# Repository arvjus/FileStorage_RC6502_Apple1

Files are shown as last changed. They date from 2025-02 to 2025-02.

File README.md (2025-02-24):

# FileStorage_RC6502_Apple1

This is a collection of HW / SW to provide file storage capabilty for RC6502 Apple1 Replica.
	
## Main Highlights
	* Uses W25Q64 chip to srore the data
	* Simple File system to keep files structured
	* Supported files: type $06 (regular binary), $F1 (Integer Basic, ProDOS file format)
	* Utility programs to prepare disk images or porsions of FS on regular OS (tested on Linux)			
	
## Status
	Quite stable, I use it on dayly basis
 
## Desired improvements
	* Better error handling. In most cases if user does input error or something unexpected happens in communication, the command is just silently ignored.
 	* Better performance in data transfer. It takes about 3 secs to load 1Kb of data.
 
## Screenshots
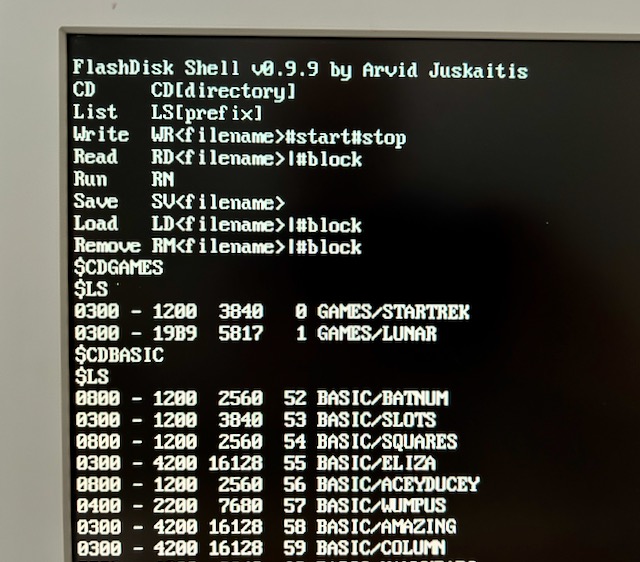
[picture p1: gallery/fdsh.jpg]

	
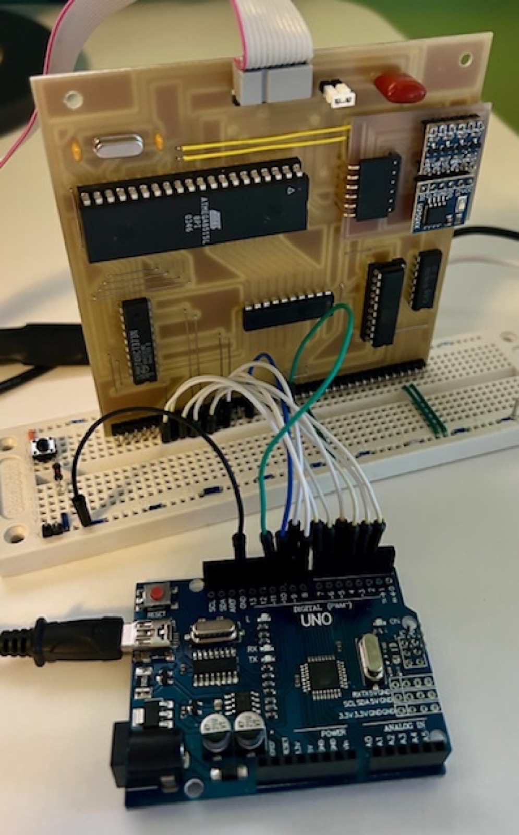
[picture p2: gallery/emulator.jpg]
emulator


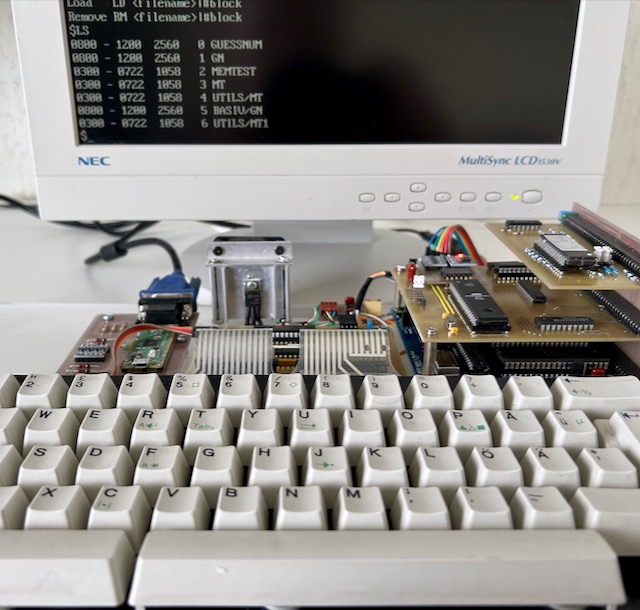
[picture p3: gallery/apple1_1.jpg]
apple1

	
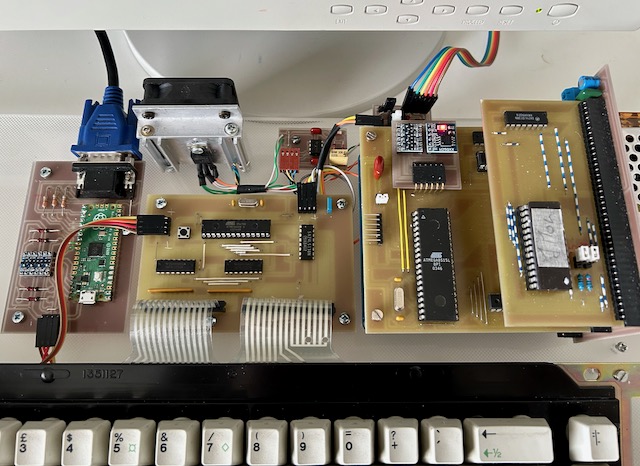
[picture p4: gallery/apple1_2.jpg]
apple1

	
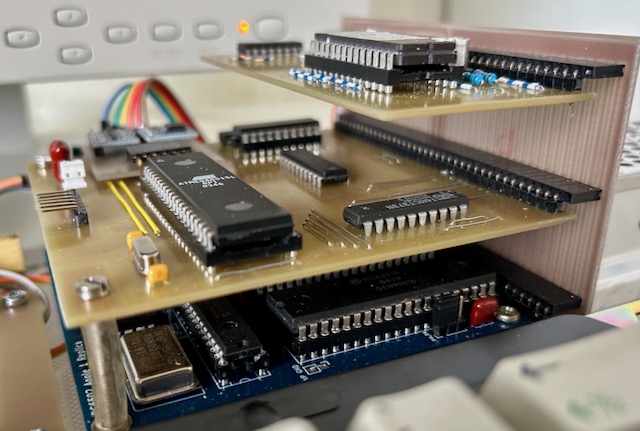
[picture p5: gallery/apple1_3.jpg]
apple1


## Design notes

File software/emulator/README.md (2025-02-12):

# CPU Emulator 

Purpose of this device is to speed up development/debugging of communication protocol and underlying file system routines. 
Based on Arduino Uno, accepts commands from serial input and communicates with RC6502_flash card, using defined data communication protocol.
Since there is only one address used ($c800), address lines can be hardwired, arduino generates /WR, PHI2 and data bus signals. 

Baud rate - 38400

emulator

##  Supported commands

### s
reads and displays byte on the data bus

### r
waits for RDY flag set, displays byte on the data bus in hex. Or reads another nibble if bytes has DAT bit set. 
For every byte received, it sends ACK automatically if received byte is other than ACK (no ACK on ACK).  

### R
similar to r, but loops until EODT is received. 

### wHH|wC
waits for BSY flag cleared, sends a byte HH in hex or two data nibbles of C.  

### a
sends ACK (0x90) byte

### n
sends NACK (0x9f) byte

### b
sends BODT (0x80) byte

### e
sends EODT (0x8f) byte

### l
print log data

### lr
reset log data

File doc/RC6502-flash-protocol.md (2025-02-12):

# RC6502 FLASH Device Data Exchange Protocol

## Overview
FLASH Device (W26Q64F) is driven by Atmega8515 MCU. This protocol ensures robust communication between the CPU and MCU, with clear mechanisms for synchronisation, acknowledgment, and error handling.

The CPU is responsible for initiating all data transfers. Communication occurs through a dedicated address range, currently set to $C800–$CFFF. There are two modes of operation: DATA and CTRL/STATUS, distinguished by the 5th bit of the byte it determines the byte type: if clear, it indicates a command (CPU) or status (MCU); if set, it represents a data nibble.

In CTRL/STATUS mode, the 5th bit is set to 0. Bits [3..0] carry commands (from the CPU) or status (from the MCU). The MCU provides two status flags: BSY (bit 6) indicates the MCU is busy, and RDY (bit 7) indicates data is ready. The CPU waits for BSY to clear before writing a byte and for RDY to be set before reading from register.

In DATA mode, the 5th bit is set to 1. Data is transmitted in nibbles using bits [3..0]. The most significant nibble (MSN) is sent first, followed by the least significant nibble (LSN).

When the CPU sends a command, the MCU replies with an ACK or NACK message. Note this is for only command, does not apply to data transfers. Similarly, when the MCU sends data to the CPU, the CPU must reply with an ACK for each byte received. If the CPU responds with NACK, the data transfer is aborted.

All data transmissions starts with begin-of-data-transfer (BODT) and concluded with an end-of-data-transfer (EODT) marker. BODT could be used to restart transmission, in some context this could mean separate data chunk, like file name and data in CMD_WRITE. If a new command is sent while a data transfer is in progress, it interrupts and cancels the current transmission.

```
## Status flags
RDY_FLAG  = (1 << 7)
BSY_FLAG  = (1 << 6)
ACK_FLAG  = (1 << 5)
DAT_FLAG  = (1 << 4)
```
```
## Commands
* CMD_LIST = 0x01     - list files. 
* CMD_WRITE = 0x02    - save data to disk. 
* CMD_READ = 0x03     - read data from disk. 
* CMD_DELETE = 0x04   - delete file.
* BODT = 0x80         - indicates the beginning of data transfer.
* EODT = 0x8F         - indicates the end of data transfer.
* ACK  = 0x90         - MCU confirms operation
* NACK = 0x9F         - MCU declines operation
```
Note in CMD_READ and CMD_DELETE commands it is possible to use block id instead of file name, eg. "#123"

## Design Issues
* Writing to MCU's input register. 6502 runs at 1 MHz clock speed, it writes to $c800 address in sync with /WR+PHI2, so we have less than 500ns window to read the data. When CPU writes data, data is latched an interrupt is triggered in MCU but IRQ latency and additional cycles delays reading for 1125ns, But after 500ns window LEWRITE- goes up and we must keep that signal low until data is read in ISR. One possible solution is to add RS latch and reset it from ISR after register is read.

## Low level data exchange protocol 
```
### CPU -> MCU
Wait for BSY is cleared
Write a command byte
Wait for RDY is set
Read a byte, ACK or NACK is expected
```
### MCU -> CPU
```
In ISR:
Set BSY, clear RDY
Read byte, check value- command, data nibble, ACK or NACK is expected
Update state in SM
If NACK is received - stop current operation.
Generate strobe CLEWRITE- to release latch
In main loop:
If a new command is initiate - start executing and return ACK or NACK
Otherwise continue with data transfer or put to idle.
```
## High level data exchange protocol

### CMD_LIST
```
; CPU rquests list all files starting with 't'
; MCU response with single file entry
; 0 Type - Unused=0, File=1, Executable=2
; 1 Block number - starting from 0
; 2-3 Length - number of bytes (little endian)
; 4-15 Name - case insensitive
; Type=File, Block=1, Length=10, Name=test.txt
CPU, MCU - CMD_LIST, ACK
CPU, MCU - BODT, ACK       	    ; File name search pattern
CPU, MCU - 0x97, ACK, 0x94, ACK ; File starts with 't'
CPU, MCU - EODT, ACK    	    ; Done
MCU, CPU - BODT, ACK            ; Start
MCU, CPU - 0x90, ACK, 0x91, ACK	; Type
MCU, CPU - 0x90, ACK, 0x91, ACK	; Block
MCU, CPU - 0x90, ACK, 0x9A, ACK	; Length LSB
MCU, CPU - 0x90, ACK, 0x90, ACK	; Length MSB
MCU, CPU - 0x97, ACK, 0x94, ACK	; 't'
MCU, CPU - 0x96, ACK, 0x95, ACK	; 'e'
MCU, CPU - 0x97, ACK, 0x93, ACK	; 's'
MCU, CPU - 0x97, ACK, 0x94, ACK	; 't'
MCU, CPU - 0x92, ACK, 0x9E, ACK	; '.'
MCU, CPU - 0x97, ACK, 0x94, ACK	; 't'
MCU, CPU - 0x97, ACK, 0x98, ACK	; 'x'
MCU, CPU - 0x97, ACK, 0x94, ACK	; 't'
MCU, CPU - EODT, ACK            ; Done
```

### CMD_WRITE
```
; write "test" string to "test.txt" file
CPU, MCU - CMD_WRITE, ACK
CPU - BODT, ACK      	; File name
CPU - 0x97, 0x94 	    ; 't'
CPU - 0x96, 0x95		; 'e'
CPU - 0x97, 0x93		; 's'
CPU - 0x97, 0x94		; 't'
CPU - 0x92, 0x9E		; '.'
CPU - 0x97, 0x94		; 't'
CPU - 0x97, 0x98		; 'x'
CPU - 0x97, 0x94		; 't'
CPU - EODT, ACK   	    ; MCU allocates file entry, could return NACK if name is invalid or no room left
CPU - BODT      		; File content
CPU - 0x97, 0x94		; 't'
CPU - 0x96, 0x95		; 'e'
CPU - 0x97, 0x93		; 's'
CPU - 0x97, 0x94		; 't'
CPU - EODT, ACK   	    ; Done
```

### CMD_READ
```
; read "empty" file
CPU, MCU - CMD_WRITE, ACK
CPU - BODT, ACK      	; File name
CPU - 0x96, 0x95		; 'e'
CPU - 0x96, 0x9D		; 'm'
CPU - 0x97, 0x90		; 'p'
CPU - 0x97, 0x94		; 't'
CPU - 0x97, 0x99		; 'y'
CPU - EODT, ACK   	; File found
MCU, CPU - BODT, ACK  ; File content
MCU, CPU - EODT, ACK  ; Done
```

### CMD_DELETE
```
; request delete non-existing file
CPU, MCU - CMD_WRITE, ACK
CPU - BODT, ACK      	; File name
CPU - 0x96, 0x9E		; 'n'
CPU - 0x96, 0x9F		; 'o'
CPU - 0x97, 0x90		; 'p'
CPU - 0x96, 0x95		; 'e'
MCU - NACK  		; File not found
```

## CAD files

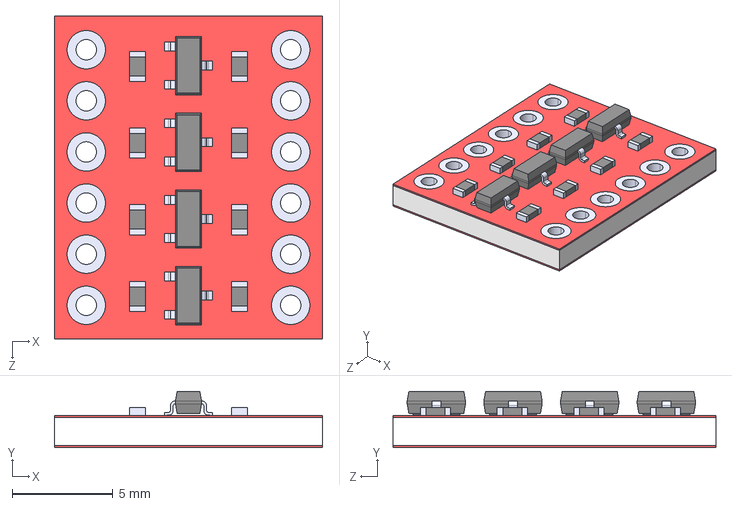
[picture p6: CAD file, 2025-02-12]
hardware/w25q64_spi/BOB-12009.step
13.3 x 2.80 x 16.1 mm

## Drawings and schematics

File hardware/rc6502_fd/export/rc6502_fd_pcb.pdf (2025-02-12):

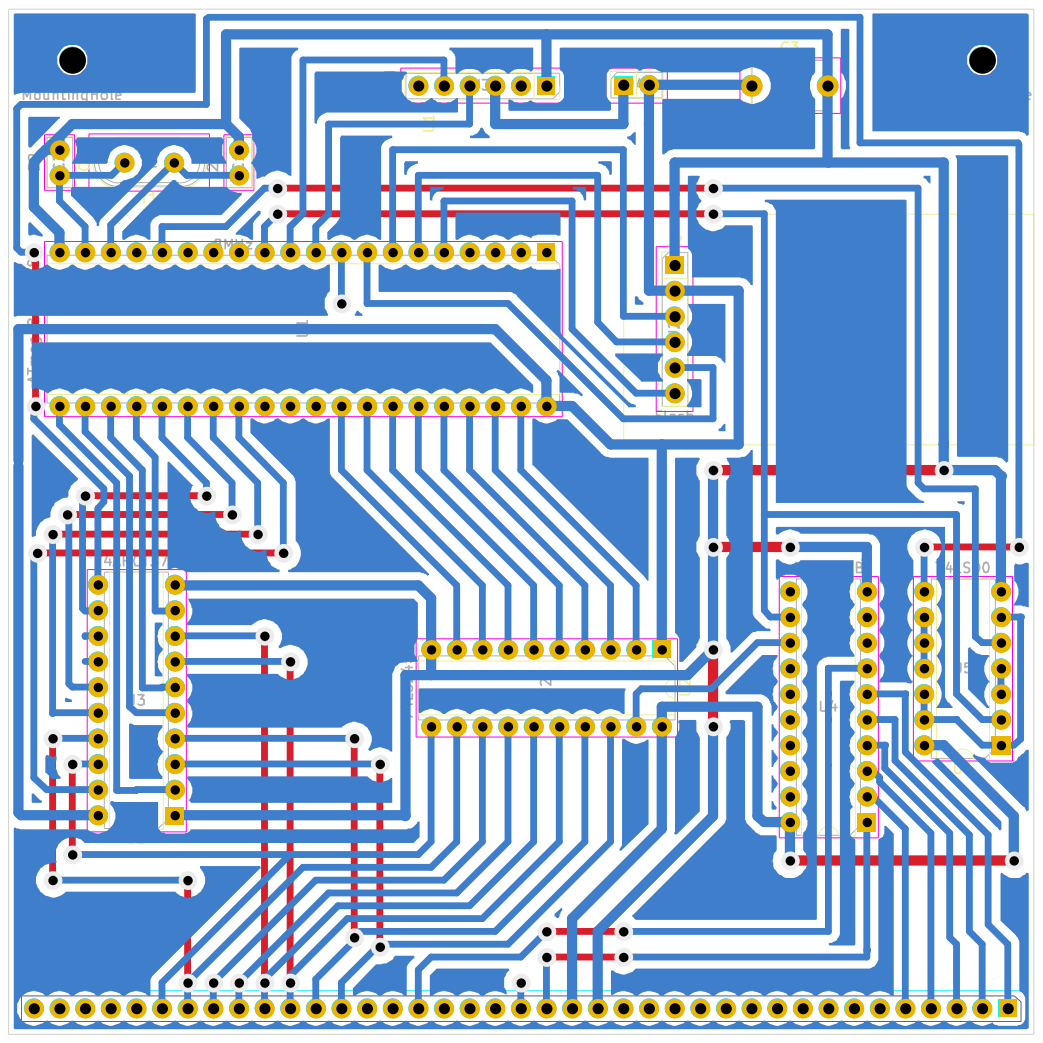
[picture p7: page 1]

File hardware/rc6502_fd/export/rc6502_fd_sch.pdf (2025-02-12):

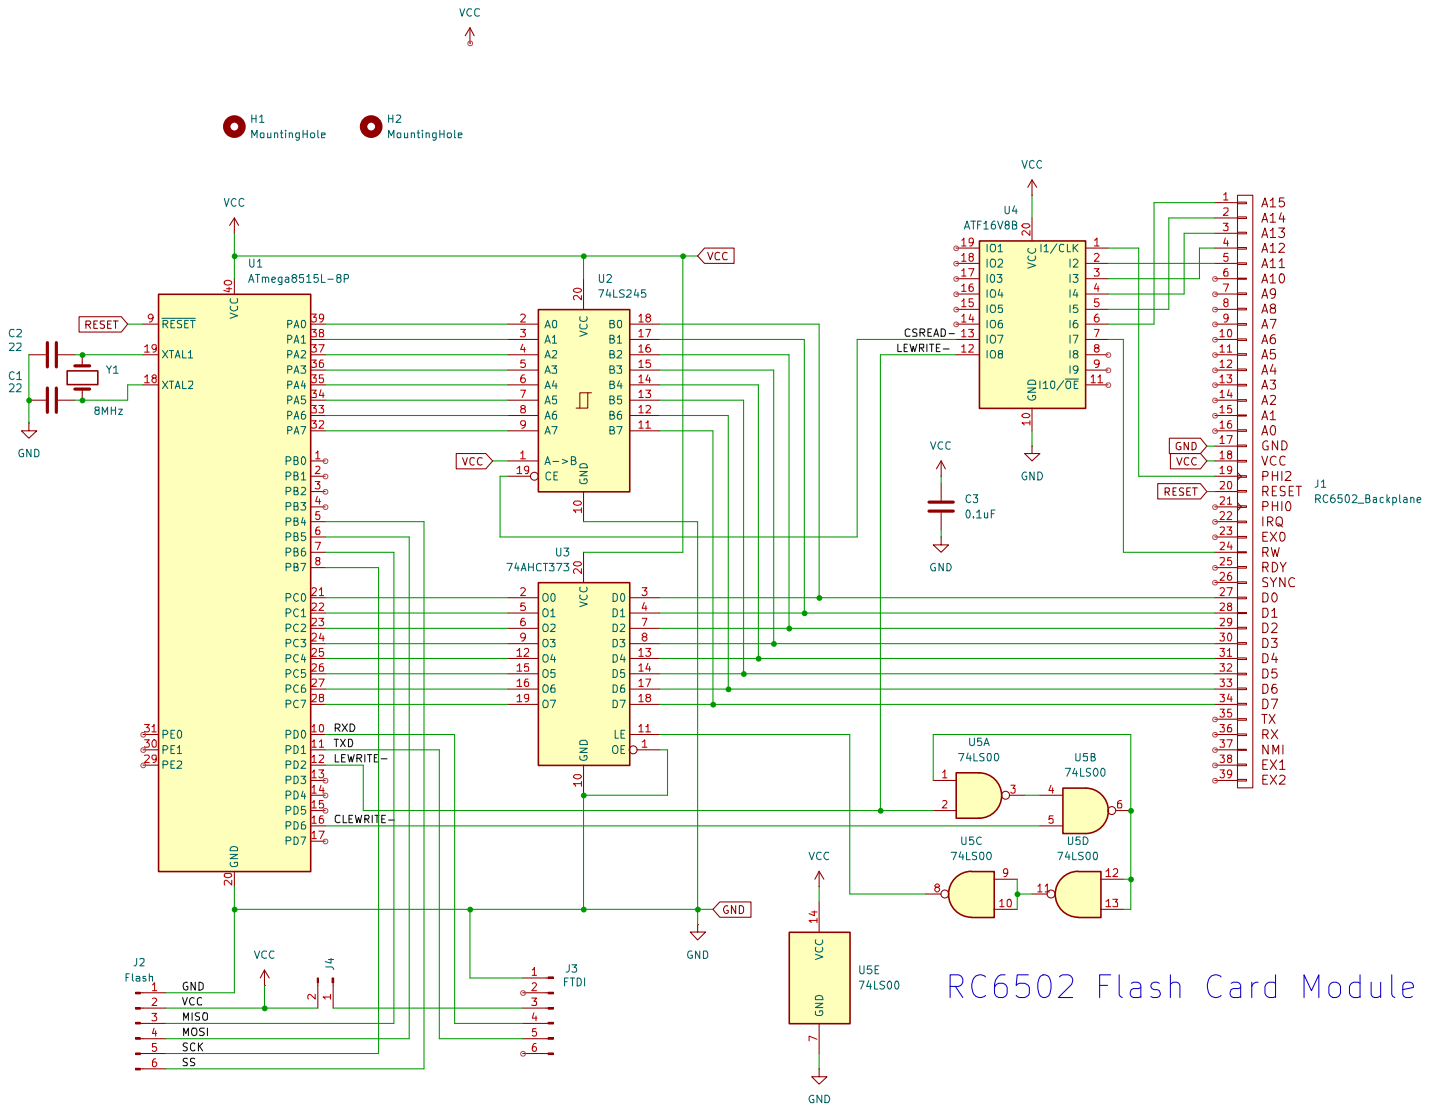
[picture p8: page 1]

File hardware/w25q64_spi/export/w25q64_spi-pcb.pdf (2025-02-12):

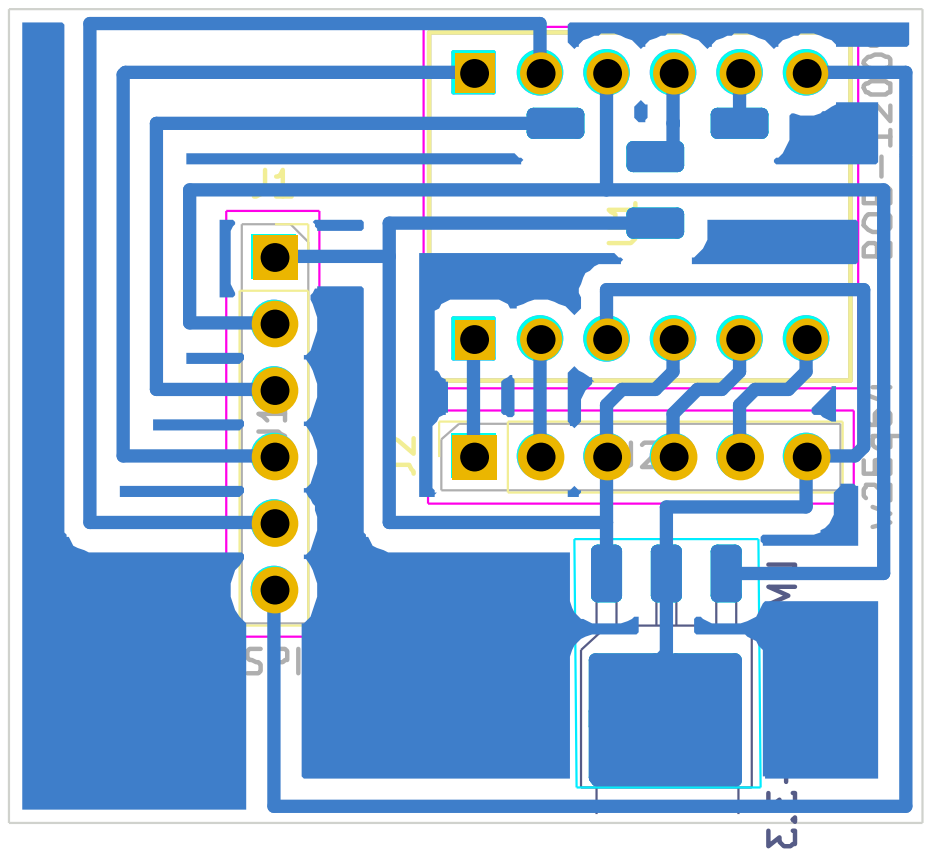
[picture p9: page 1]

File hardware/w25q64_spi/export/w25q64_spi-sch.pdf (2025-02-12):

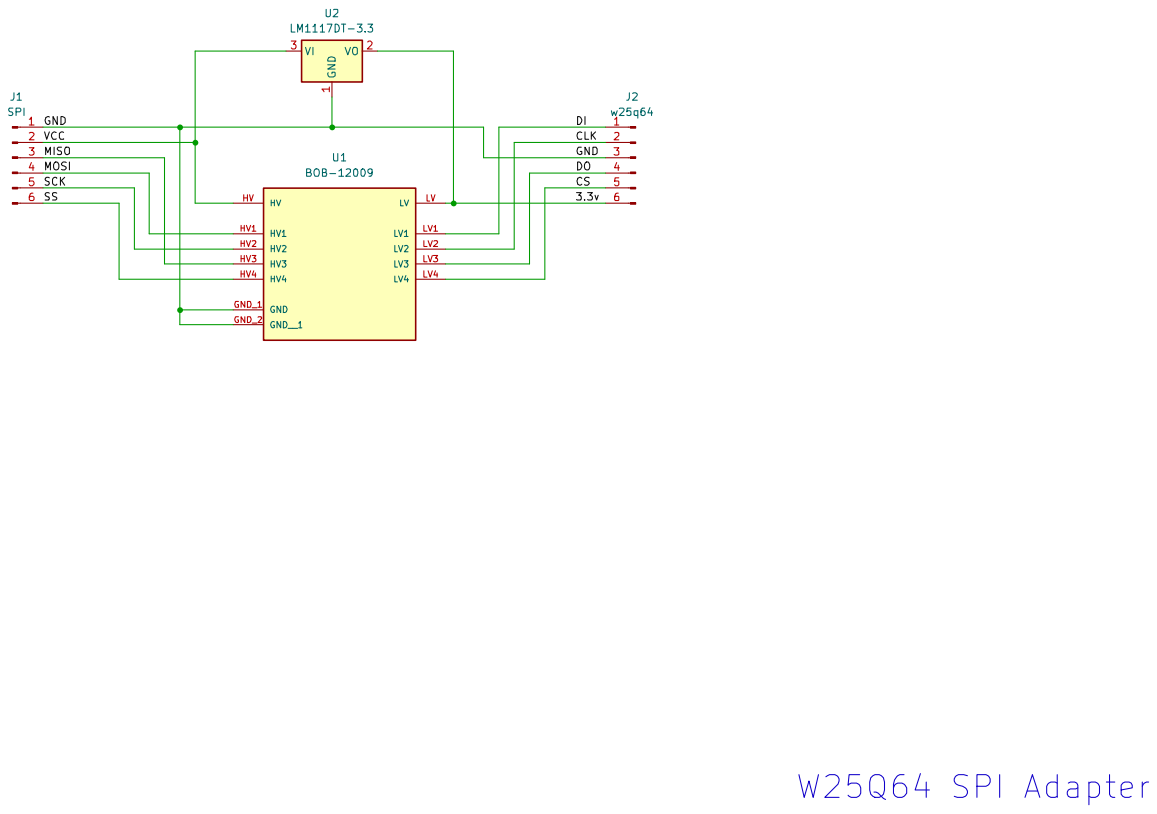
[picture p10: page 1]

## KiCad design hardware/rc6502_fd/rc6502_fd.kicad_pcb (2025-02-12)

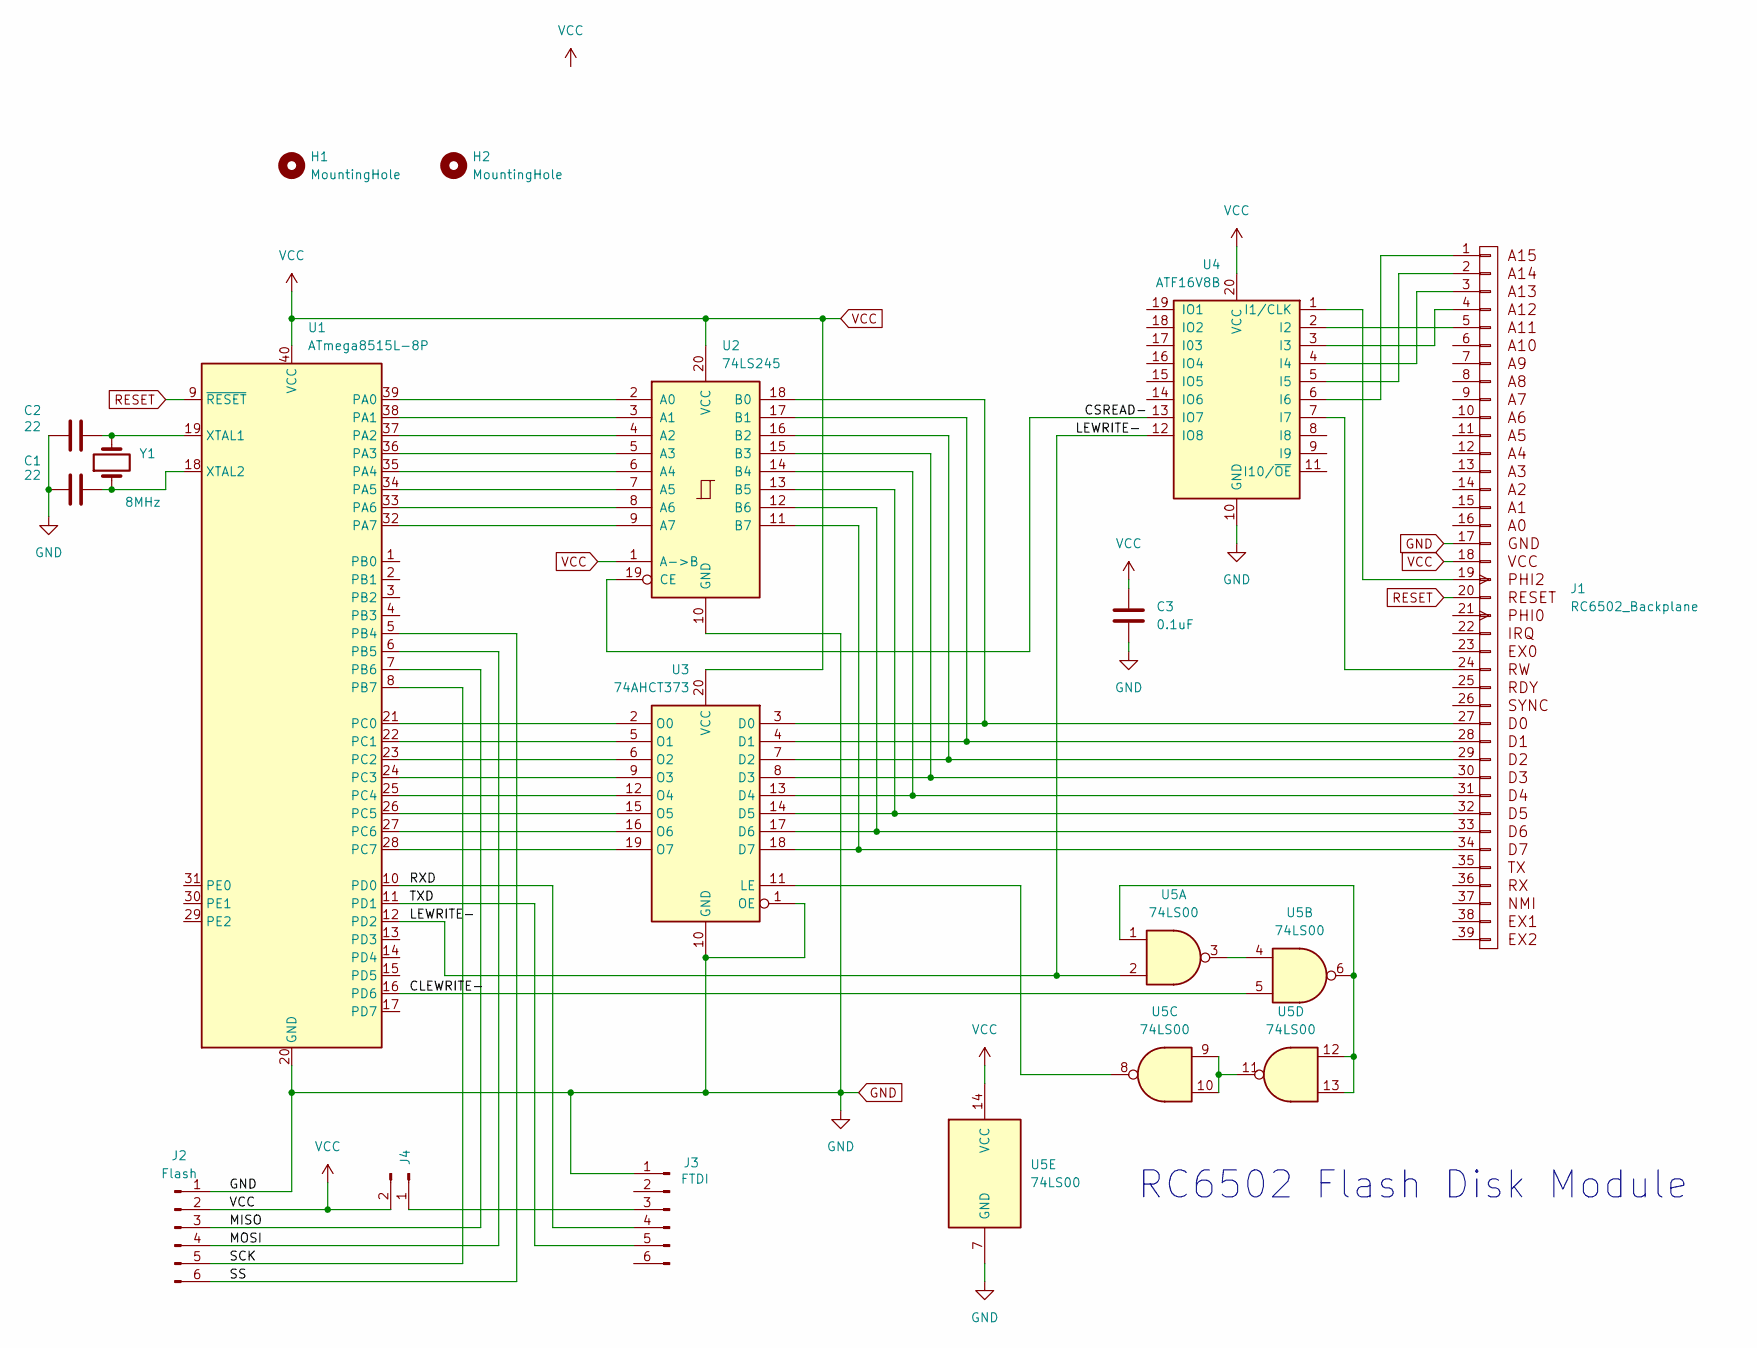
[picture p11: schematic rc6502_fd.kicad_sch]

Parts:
C1, C2: 22; C_Disc_D5.0mm_W2.5mm_P2.50mm
C3: 0.1uF; C_Disc_D7.5mm_W5.0mm_P7.50mm
H1, H2: MountingHole; MountingHole_2.5mm
J1: RC6502_Backplane; PinSocket_1x39_P2.54mm_Vertical
J2: Flash; PinHeader_1x06_P2.54mm_Vertical
J3: FTDI; PinSocket_1x06_P2.54mm_Vertical
J4: Conn_01x02_Pin; PinSocket_1x02_P2.54mm_Vertical
U1: ATmega8515L-8P; DIP-40_W15.24mm
U2: 74LS245; DIP-20_W7.62mm
U3: 74AHCT373; DIP-20_W7.62mm
U4: ATF16V8B; DIP-20_W7.62mm
U5: 74LS00; DIP-14_W7.62mm
Y1: 8MHz; Crystal_HC18-U_Vertical

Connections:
/CLEWRITE-: U1.16 (PD6), U5.5
/CSREAD-: U2.19 (CE), U4.13 (IO7)
/LEWRITE-: U1.12 (PD2), U4.12 (IO8), U5.2
/MISO: J2.3, U1.7 (PB6)
/MOSI: J2.4, U1.6 (PB5)
/RXD: J3.4, U1.10 (PD0)
/SCK: J2.5, U1.8 (PB7)
/SS: J2.6, U1.5 (PB4)
/TXD: J3.5, U1.11 (PD1)
GND: C1.1, C2.1, C3.2, J1.17, J2.1, J3.1, U1.20 (GND), U2.10 (GND), U3.1 (OE), U3.10 (GND), U4.10 (GND), U5.7 (GND)
unnamed: J1.5 (A11), U4.2 (I2)
unnamed: J1.4 (A12), U4.3 (I3)
unnamed: J1.3 (A13), U4.4 (I4)
unnamed: J1.2 (A14), U4.5 (I5)
unnamed: J1.1 (A15), U4.6 (I6)
unnamed: J1.27 (D0), U2.18 (B0), U3.3 (D0)
unnamed: J1.28 (D1), U2.17 (B1), U3.4 (D1)
unnamed: J1.29 (D2), U2.16 (B2), U3.7 (D2)
unnamed: J1.30 (D3), U2.15 (B3), U3.8 (D3)
unnamed: J1.31 (D4), U2.14 (B4), U3.13 (D4)
unnamed: J1.32 (D5), U2.13 (B5), U3.14 (D5)
unnamed: J1.33 (D6), U2.12 (B6), U3.17 (D6)
unnamed: J1.34 (D7), U2.11 (B7), U3.18 (D7)
unnamed: J1.19 (PHI2), U4.1 (I1/CLK)
unnamed: J1.24 (RW), U4.7 (I7)
unnamed: J3.3, J4.1
unnamed: U1.39 (PA0), U2.2 (A0)
unnamed: U1.38 (PA1), U2.3 (A1)
unnamed: U1.37 (PA2), U2.4 (A2)
unnamed: U1.36 (PA3), U2.5 (A3)
unnamed: U1.35 (PA4), U2.6 (A4)
unnamed: U1.34 (PA5), U2.7 (A5)
unnamed: U1.33 (PA6), U2.8 (A6)
unnamed: U1.32 (PA7), U2.9 (A7)
unnamed: U1.21 (PC0), U3.2 (O0)
unnamed: U1.22 (PC1), U3.5 (O1)
unnamed: U1.23 (PC2), U3.6 (O2)
unnamed: U1.24 (PC3), U3.9 (O3)
unnamed: U1.25 (PC4), U3.12 (O4)
unnamed: U1.26 (PC5), U3.15 (O5)
unnamed: U1.27 (PC6), U3.16 (O6)
unnamed: U1.28 (PC7), U3.19 (O7)
unnamed: C2.2, U1.19 (XTAL1), Y1.2
unnamed: C1.2, U1.18 (XTAL2), Y1.1
unnamed: U3.11 (LE), U5.8
unnamed: U5.1, U5.6, U5.12, U5.13
unnamed: U5.3, U5.4
unnamed: U5.9, U5.10, U5.11
RESET: J1.20 (RESET), U1.9 (~RESET)
VCC: C3.1, J1.18, J2.2, J4.2, U1.40 (VCC), U2.1 (A->B), U2.20 (VCC), U3.20 (VCC), U4.20 (VCC), U5.14 (VCC)

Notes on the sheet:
RC6502 Flash Disk Module

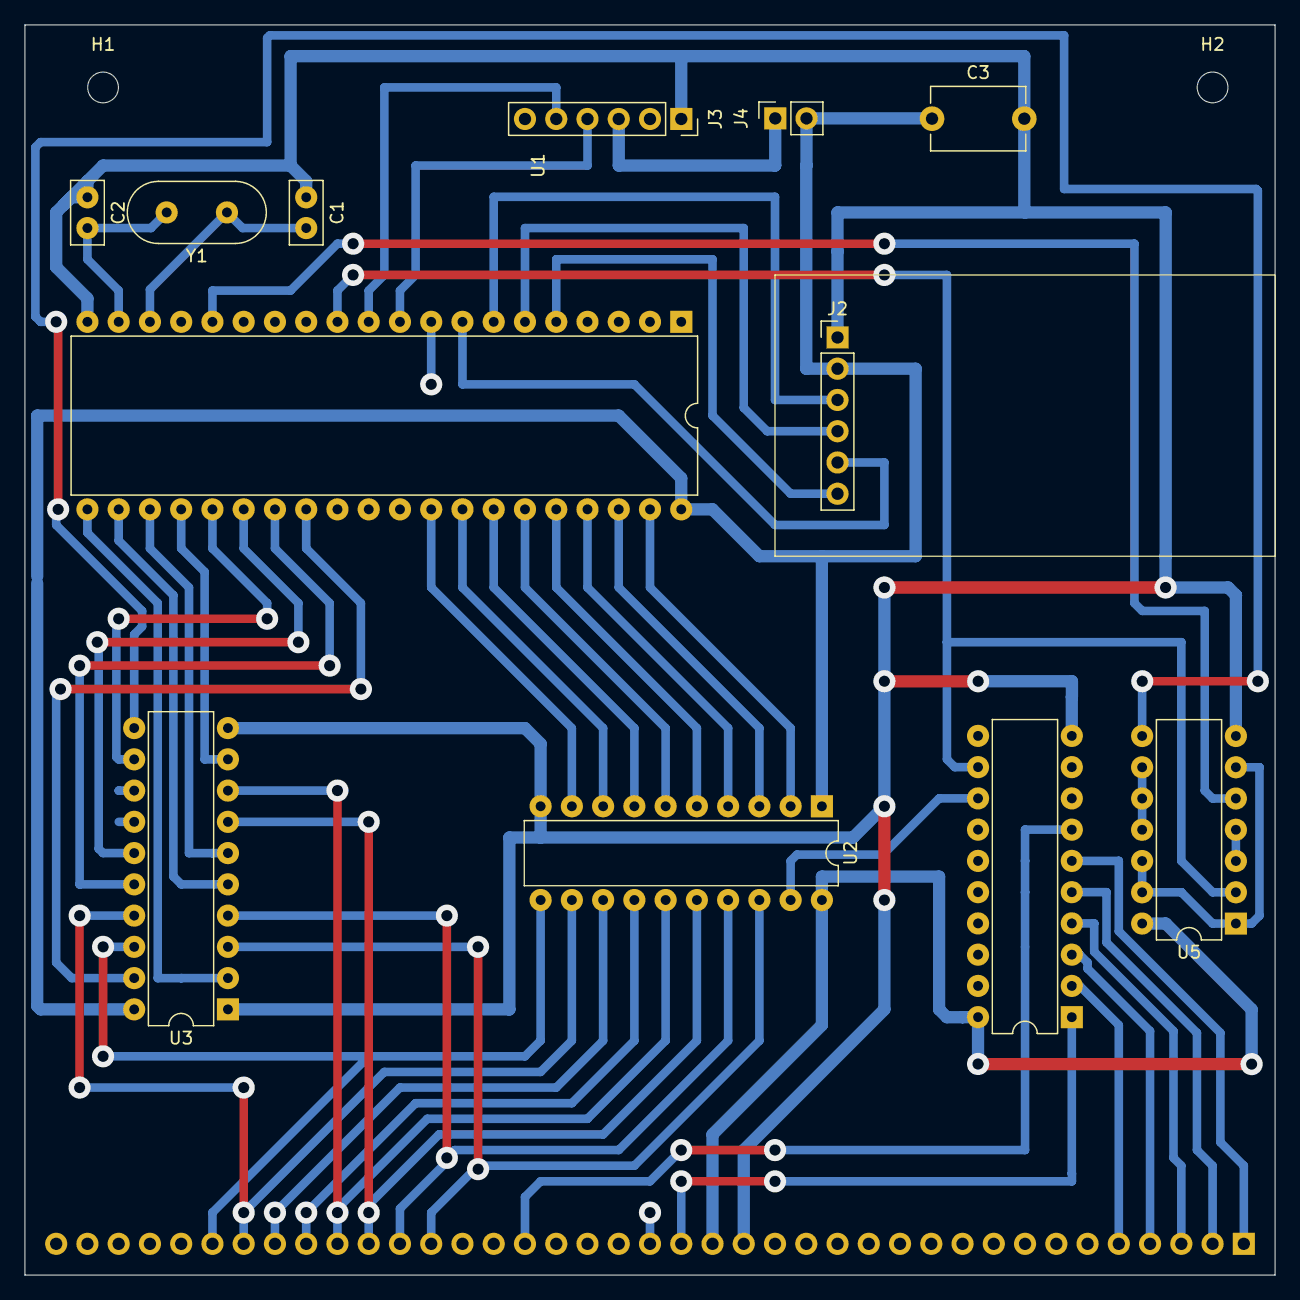
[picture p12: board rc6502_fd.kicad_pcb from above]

Board: 2 copper layers, 101.6 x 101.6 mm, 15 parts (1 on the bottom side), 50 nets.

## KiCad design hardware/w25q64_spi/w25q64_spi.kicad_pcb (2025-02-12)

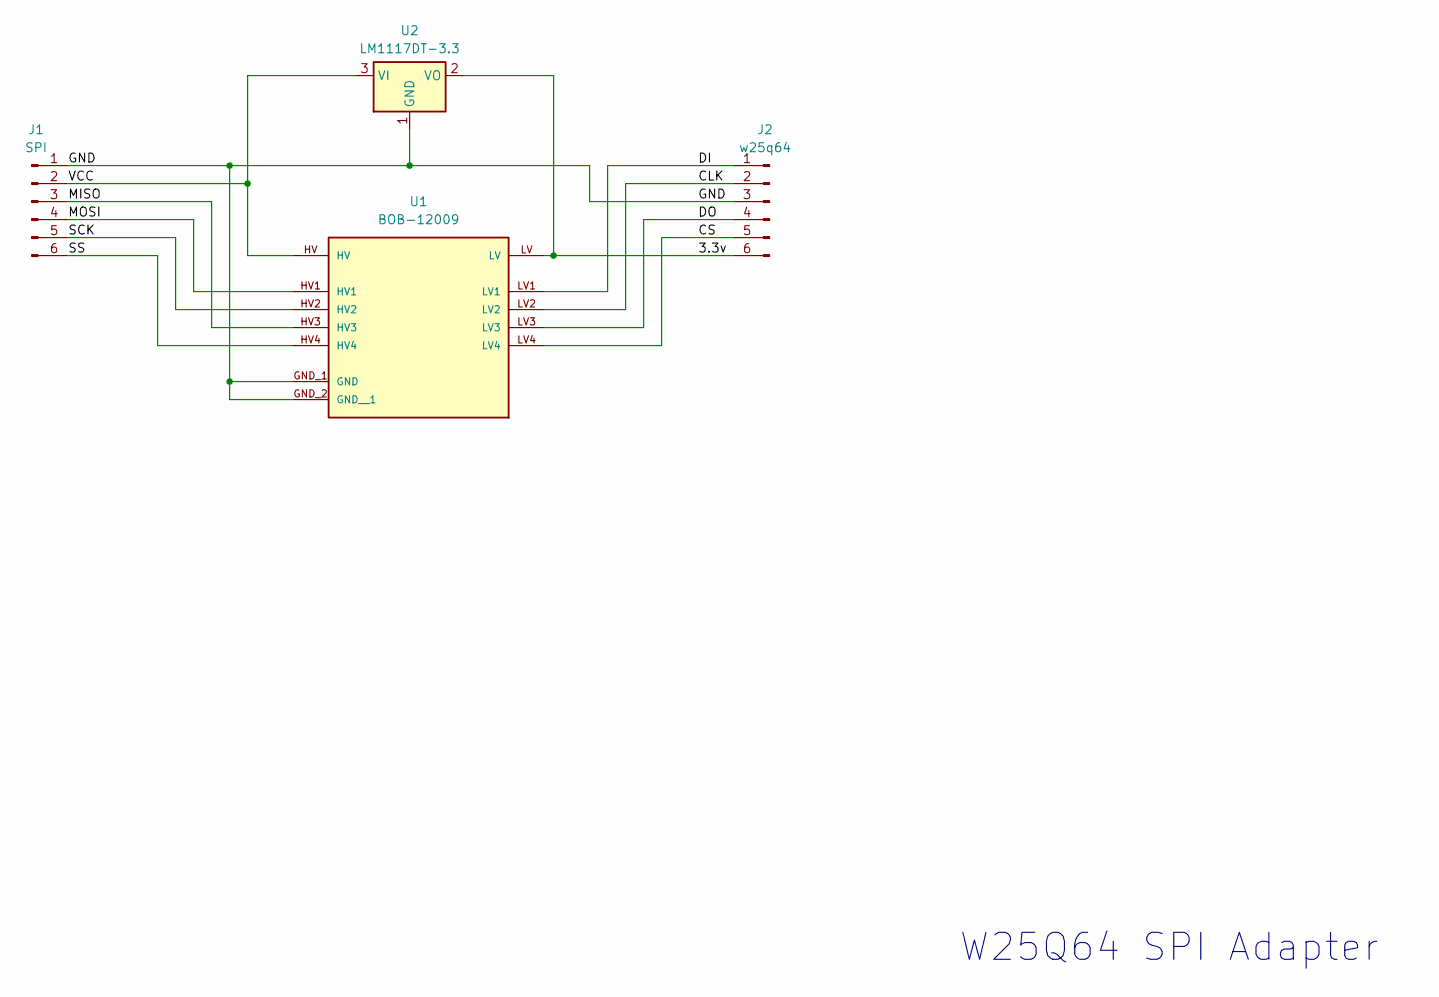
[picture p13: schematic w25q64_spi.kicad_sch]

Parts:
J1: SPI; PinSocket_1x06_P2.54mm_Vertical
J2: w25q64; PinSocket_1x06_P2.54mm_Vertical
U1: BOB-12009; CONV_BOB-12009; PARTREV 01
U2: LM1117DT-3.3; TO-252-3_TabPin2

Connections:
/3.3v: J2.6, U1.LV, U2.2 (VO)
/CLK: J2.2, U1.LV2
/CS: J2.5, U1.LV4
/DI: J2.1, U1.LV1
/DO: J2.4, U1.LV3
/GND: J1.1, J2.3, U1.GND_1 (GND), U1.GND_2 (GND__1), U2.1 (GND)
/MISO: J1.3, U1.HV3
/MOSI: J1.4, U1.HV1
/SCK: J1.5, U1.HV2
/SS: J1.6, U1.HV4
/VCC: J1.2, U1.HV, U2.3 (VI)

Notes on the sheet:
W25Q64 SPI Adapter

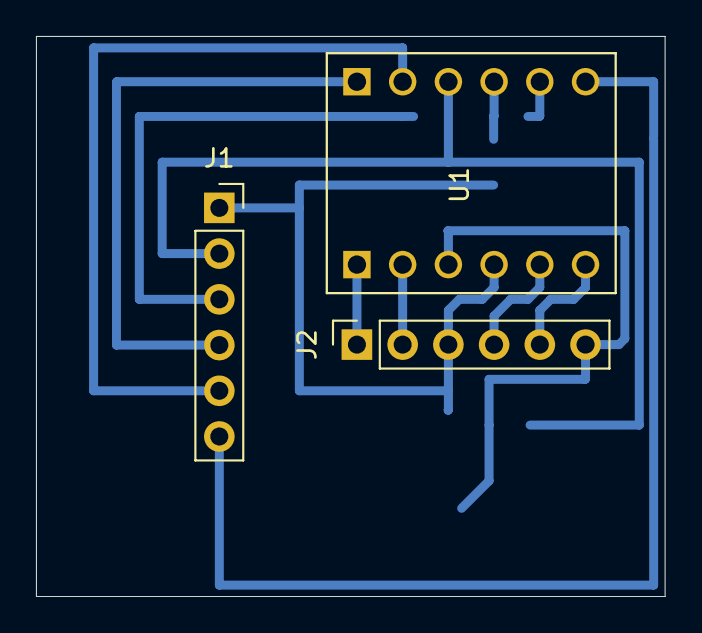
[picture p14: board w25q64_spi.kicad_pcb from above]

Board: 2 copper layers, 34.9 x 31.1 mm, 4 parts (1 on the bottom side), 11 nets.

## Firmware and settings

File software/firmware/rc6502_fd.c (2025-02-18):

/*
RC6502 FLASH (W25Q64F) Card firmware

PINC  - CPU -> MCU
PORTA - MCU -> CPU
PD2   - LEWRITE-
PD6   - CLEWRITE-
*/

#include <string.h>
#include <stdlib.h>
#include <stdbool.h>
#include <avr/io.h>
#include <avr/interrupt.h>
#include <util/delay.h>
#include "simplefs.h"
#include "uart.h"

#define DEBUG   0
#define BAUD 250000

/* ------------------------------------------------------------------------
 *  Protocol constants
 * ------------------------------------------------------------------------
 */

// Status bits
#define RDY_FLAG    (1 << 7)  // MCU sets if data is ready
#define BSY_FLAG    (1 << 6)  // MCU sets if busy
#define ACK_FLAG    (1 << 5)  // ACK, NACK
#define DAT_FLAG    (1 << 4)  // Data nibble flag

// Commands
#define CMD_RESET   0x00
#define CMD_LIST    0x01
#define CMD_READ    0x02
#define CMD_WRITE   0x03
#define CMD_DELETE  0x04

// Markers - Note by setting markers we're setting RDY_FLAG and clearing BSY_FLAG
#define BODT        0x80
#define EODT        0x8F
#define ACK         0xA0
#define NACK        0xAF

/* ------------------------------------------------------------------------
 *  Ports / Bit manipulation
 * ------------------------------------------------------------------------
 */
#define MCU_IN          PINC
#define MCU_OUT         PORTA

#define SET_RDY_FLAG()  (MCU_OUT |= RDY_FLAG)
#define CLR_RDY_FLAG()  (MCU_OUT &= ~RDY_FLAG)

#define SET_BSY_FLAG()  (MCU_OUT |= BSY_FLAG)
#define CLR_BSY_FLAG()  (MCU_OUT &= ~BSY_FLAG)

#define SET_DAT_FLAG()  (MCU_OUT |= DAT_FLAG)
#define CLR_DAT_FLAG()  (MCU_OUT &= ~DAT_FLAG)

#define SET_CLEWRITE()  (PORTD |= (1 << PD6))
#define CLR_CLEWRITE()  (PORTD &= ~(1 << PD6))

// State machine enumerations
typedef enum {
    SM_IDLE = 0,            // Doing nothing, waiting for next command from CPU
    SM_RECEIVE_CMD = 1,     // We are receiving a new command
    SM_PROCESS_CMD = 2,     // We have a command to process
    SM_SEND_DATA = 3,       // We are sending data back to CPU
    SM_RECEIVE_DATA = 4,    // We are receiving data from CPU
    SM_FINISH = 5,          // We are about to finish with current command
} mcu_state_t;

// global variables
volatile uint8_t state = SM_IDLE;
volatile uint8_t command = 0, ms_nibble = 0;
volatile uint16_t block = 0;
volatile bool handle_disk_data = false; // set true to request more data for CMD_LIST and CMD_READ, set true to flush data for CMD_WRITE
volatile uint16_t buff_idx = 0, buff_max = 0, file_size = 0;
volatile uint8_t buff[PAGE_SIZE];
char buff_aux[MAX_NAME_SIZE];

// forward declarations
void init_mcu();
void reset();
void send_data_nibble();
bool handle_cmd_list(bool init);
bool handle_cmd_read(bool initial);
bool handle_cmd_write(bool initial);
bool handle_cmd_delete();
#if BULK_TRANSFER
void bulk_erase();
void bulk_read();
void bulk_write();
#endif            
#if DEBUG
void value_to_hex(uint8_t value);
void print_msg(const char *msg);
void print_msg_string(const char *msg, const char *value);
void print_msg_hex(const char *msg, uint16_t value);
void print_status();
void print_buffer();
#else
#define print_msg(msg)              /**/
#define print_msg_string(msg,value) /**/
#define print_msg_hex(msg,value)    /**/
#define print_status()              /**/
#define print_buffer()              /**/
#endif

int main(void) {
    init_mcu();
    if (W25Q64FV_begin(PB4) == W25Q64FV_OK)
        print_msg("FD ");

    reset();
    MCU_OUT = 0x00; // not busy, not ready
    while (1) {
        // Check for UART command
        if (uart_available()) {
            uint8_t ch = uart_receive();
            if (ch == 'r') reset();
            else if (ch == 's') print_status();
            else if (ch == 'b') print_buffer();
#if BULK_TRANSFER
            else if (ch == 'E') bulk_erase();
            else if (ch == 'R') bulk_read();
            else if (ch == 'W') bulk_write();
#endif            
        }

        switch (state) {
            case SM_IDLE:
                break;

            case SM_PROCESS_CMD:
                // New request from CPU, buff contains request data
                switch (command) {
                    case CMD_LIST:
                        if (handle_cmd_list(true)) {
                            state = SM_SEND_DATA;
                            MCU_OUT = BODT;
                        } else {
                            state = SM_IDLE;
                            MCU_OUT = EODT;
                        }
                        break;
                    case CMD_READ:
                        if (handle_cmd_read(true)) {
                            state = SM_SEND_DATA;
                            MCU_OUT = BODT;
                        } else {
                            state = SM_IDLE;
                            MCU_OUT = EODT;
                        }
                        break;
                    case CMD_WRITE:
                        if (handle_cmd_write(true)) {
                            state = SM_RECEIVE_DATA;
                            MCU_OUT = ACK;
                        } else {
                            state = SM_IDLE;
                            MCU_OUT = NACK;
                        }
                        break;
                    case CMD_DELETE:
                        if (handle_cmd_delete()) {
                            MCU_OUT = ACK;
                        } else {
                            MCU_OUT = NACK;
                        }
                        state = SM_IDLE;
                        break;
                }
                break;

            case SM_SEND_DATA:
                if (command == CMD_LIST && handle_disk_data) {
                    handle_disk_data = false;
                    if (handle_cmd_list(false)) {
                        send_data_nibble();
                    } else {
                        state = SM_FINISH;
                        MCU_OUT = EODT;
                    }
                } else if (command == CMD_READ && handle_disk_data) {
                    handle_disk_data = false;
                    if (buff_max == PAGE_SIZE && handle_cmd_read(false)) {
                        send_data_nibble();
                    } else {
                        state = SM_FINISH;
                        MCU_OUT = EODT;
                    }
                }
                break;
            case SM_FINISH:
            case SM_RECEIVE_DATA:
                if (command == CMD_WRITE && handle_disk_data) {
                    handle_disk_data = false;
                    if (handle_cmd_write(false)) {
                        if (buff_max == 0) {
                            reset();
                        }
                        MCU_OUT = ACK;
                    } else {
                        MCU_OUT = NACK;
                    }
                }
                break;
            default:
                break;
        }
    }
}

// Interrupt Service Routine for INT0
ISR(INT0_vect) {
    // Set BSY_FLAG, clear RDY_FLAG
    MCU_OUT = BSY_FLAG;

    uint8_t in_byte = MCU_IN;
#if DEBUG
    value_to_hex(in_byte);
    uart_transmit_string(buff_aux);
#endif
    if (in_byte & DAT_FLAG) {
        if (state == SM_RECEIVE_CMD || state == SM_RECEIVE_DATA) {
            if (buff_idx < sizeof(buff)) {
                if (ms_nibble) {
                    buff[buff_idx ++] = ((ms_nibble & 0x0f) << 4) | (in_byte & 0x0f);
                    ms_nibble = 0;
                    if (buff_idx >= sizeof(buff)) {
                        handle_disk_data = true;
                    }                  
                } else {
                    ms_nibble = in_byte;
                }
            } else {
                print_msg("MEM!");  // we're out of bounds - very bad
            }
            if (!handle_disk_data) {
                MCU_OUT = ACK;
            }
        }
    } else {
        // 5th bit not set -> control/status mode
        switch (in_byte) {
            case CMD_RESET:
                reset();
                MCU_OUT = ACK;
                break;
            case CMD_LIST:
            case CMD_READ:
            case CMD_WRITE:
            case CMD_DELETE:
                command = in_byte;
                state = SM_RECEIVE_CMD;
                buff_max = MAX_NAME_SIZE;  // max number of bytes to transfer
                buff_idx = 0;   // from 0
                ms_nibble = 0;  // no last nibble
                handle_disk_data = false;
                MCU_OUT = ACK;
                break;
            case BODT:
                MCU_OUT = ACK;
                break;
            case EODT:
                if (state == SM_RECEIVE_CMD) {
                    // here have we received command, start processing..
                    buff[buff_idx] = '\0';
                    state = SM_PROCESS_CMD;
                } else if (command == CMD_WRITE && state == SM_RECEIVE_DATA) {
                    // finish writing rest of data to disk
                    state = SM_FINISH;
                    MCU_OUT = ACK;
                    handle_disk_data = true;
                }
                break;
            case ACK:
                switch (command) {
                    case CMD_LIST:
                    case CMD_READ:
                        if (state == SM_SEND_DATA) {
                            if (buff_idx < buff_max) {
                                send_data_nibble();
                            } else {            // end of buffer
                                handle_disk_data = true;
                            }
                        }
                        break;
                    case CMD_WRITE:
                    case CMD_DELETE:
                        break;
                    default:
                        print_msg("ACK?");
                        break;
                }

                if (state == SM_FINISH) {
                    print_msg("FIN");
                    reset();
                    MCU_OUT = 0x00;     // not busy, not ready
                }
                CLR_BSY_FLAG();
                break;
            case NACK:
                print_msg("NACK");
                reset();
                MCU_OUT = 0x00; // not busy, not ready
                break;
            default:
                // Some other status or control byte
                break;
        }
    }

    // Strobe CLEWRITE for 1 ms
    CLR_CLEWRITE();
    _delay_ms(1);
    SET_CLEWRITE();
}


void init_mcu() {
    // Initialize UART with calculated UBRR
    uart_init(F_CPU / 16 / BAUD - 1);
#if DEBUG
    // Send a string over UART
    print_msg("RC6502 ");
#endif

    // Configure PORTA, PINC
    DDRA = 0xff;    // output
    DDRC = 0x00;    // input

    // Configure PD6 as an output and set it high
    DDRD |= (1 << PD6);  // Set PD6 as output
    PORTD |= (1 << PD6); // Set PD6 high

    // Configure PD2 (INT0) for falling edge trigger
    MCUCR |= (1 << ISC01);  // ISC01 = 1, ISC00 = 0 for falling edge
    MCUCR &= ~(1 << ISC00); // Ensure ISC00 is 0

    // Enable external interrupt INT0
    GICR |= (1 << INT0);

    // Enable global interrupts
    sei();
}

void reset() {
    print_msg("RST");
    state = SM_IDLE;
    command = 0;
    block = 0;
    ms_nibble = 0;
    buff_max = 0;
    buff_idx = 0;
    handle_disk_data = false;
    file_size = 0;
}

void send_data_nibble() {
    if (ms_nibble == 0) {
        MCU_OUT = RDY_FLAG | DAT_FLAG | ((buff[buff_idx] >> 4) & 0x0f);
        ms_nibble = DAT_FLAG;
    } else {
        MCU_OUT = RDY_FLAG | DAT_FLAG | (buff[buff_idx] & 0x0f);
        ms_nibble = 0;
        buff_idx++;
    }
}

bool handle_cmd_list(bool initial) {
#if LIST
    buff_max = sizeof(FileEntry_t);  // number of bytes to transfer
    buff_idx = 0;   // reset index
    ms_nibble = 0;  // no last nibble
    // SimpleFS_listFiles will use 32 bytes of the buff, so we can reuse other space in th buffer
    char* prefix = (char*)buff + 100;
    if (initial) {
        memcpy(prefix, (const char*)buff, MAX_NAME_SIZE);
        block = 0;
        print_msg_string("L!", prefix);
    } else {
        block ++;
    }

    uint8_t status = SimpleFS_listFiles((uint8_t*)buff, (uint16_t*)&block, prefix);
    if (status != OK && status != FILE_ENTRY_IS_NOT_FOUND) {
        buff_max = 0;
        print_msg_hex("err:", status);
    }
    return status == OK; // true if buffer contains a valid file entry
#else
    return false;
#endif
}

bool handle_cmd_read(bool initial) {
#if READ
    buff_max = PAGE_SIZE;
    buff_idx = 0;   // reset index
    ms_nibble = 0;  // no last nibble
    uint8_t status;
    if (initial) {
        print_msg_string("R!", (const char *)buff);
        if (*buff == '#') {
            status = SimpleFS_readFileByBlockNo((uint8_t*)buff, (uint8_t)atoi((const char*)buff+1), (uint16_t*)&file_size);
        } else {
            memcpy(buff_aux, (const char*)buff, sizeof(buff_aux));
            status = SimpleFS_readFileByName((uint8_t*)buff, buff_aux, (uint16_t*)&file_size);
        }
    } else {
        status = SimpleFS_readFileNextPage((uint8_t*)buff);
    }
    if (status == OK) {
        buff_max = file_size < PAGE_SIZE ? file_size : PAGE_SIZE;
        file_size -= buff_max;  // we already have page in the buffer
    } else {
        print_msg_hex("err:", status);
    }
    return status == OK; // true if buffer contains a valid data
#else
    return false;
#endif
}

bool handle_cmd_write(bool initial) {
#if WRITE
    uint8_t status;
    if (initial) {          // create a file structure first
        print_msg_string("W!", (const char *)buff);
        memcpy(buff_aux, (const char*)buff, sizeof(buff_aux));
        uint16_t block = 0;  // A new entry will be allocated starting from this block
        status = SimpleFS_createFileEntry((uint8_t*)buff, buff_aux, &block, (uint16_t*)&file_size);
        buff_max = file_size < PAGE_SIZE ? file_size : PAGE_SIZE;
        buff_idx = sizeof(FileEntry_t);
        ms_nibble = 0;  // no last nibble
        print_status();
    } else {
        print_msg_string("W!", "");
        print_status();
        print_buffer();
        status = SimpleFS_writeFile((uint8_t*)buff);
        file_size -= buff_max;
        buff_max = file_size < PAGE_SIZE ? file_size : PAGE_SIZE;
        buff_idx = 0;
        print_status();
    }
    if (status != OK) {
        print_msg_hex("err:", status);
    }
    return status == OK; // true if data is written and needs more to write
#else
    return false;
#endif
}

bool handle_cmd_delete() {
#if DELETE
    uint8_t status;
    print_msg_string("D!", (const char *)buff);
    if (*buff == '#') {
        status = SimpleFS_deleteFileByBlockNo((uint8_t*)buff, (uint8_t)atoi((const char*)buff+1));
    } else {
        memcpy(buff_aux, (const char*)buff, sizeof(buff_aux));
        status = SimpleFS_deleteFileByName((uint8_t*)buff, buff_aux);
    }
    if (status != OK && status != FILE_ENTRY_IS_NOT_FOUND) {
        print_msg_hex("err:", status);
    }
    return status == OK; // true if buffer contains a valid data
#else
    return false;
#endif
}

#if DEBUG
void value_to_hex(uint8_t value) {
    buff_aux[0] = '0';
    itoa(value, value < 0xf ? &buff_aux[1] : buff_aux, 16);
    buff_aux[2] = ' ';
    buff_aux[3] = '\0';
}

void print_msg(const char *msg) {
    uart_transmit_string(msg);
}

void print_msg_string(const char *msg, const char *value) {
    uart_transmit_string(msg);
    uart_transmit_string(value);
}

void print_msg_hex(const char *msg, uint16_t value) {
    uart_transmit_string(msg);
    itoa(value, buff_aux, 16);
    uart_transmit_string(buff_aux);
}

void print_status() {
    print_msg_hex("st:", state);
    print_msg_hex(",cmd:", command);
    print_msg_hex(",idx:", buff_idx);
    print_msg_hex(",max:", buff_max);
    print_msg_hex(",fs:", file_size);
}
void print_buffer() {
    for (int i = 0; i < buff_max; i++) {
        value_to_hex(buff[i]);
        uart_transmit_string(buff_aux);
    }
}
#endif

#if BULK_TRANSFER
#include "w25q64fv.h"
// two bytes are expected- number of pages in binary, little endian. 
uint16_t receive_uint16() {
    while (!uart_available());
    uint8_t lsb = uart_receive();
    while (!uart_available());
    uint8_t msb = uart_receive();
    return (msb << 8) | lsb;
}

// one parameter is expected.
// size - number of 32k blocks to erase. if 0 is given, all chip is erased
void bulk_erase() {
    uint16_t size = receive_uint16();
    if (size) {
        W25Q64FV_status_t status = W25Q64FV_OK;
        for (int i = 0; i < size && status == W25Q64FV_OK; i++) {
            uint32_t address = ((uint32_t)i) * PAGE_SIZE;
            status = W25Q64FV_erase_block_32(address, true);
        }
        uart_transmit(status == W25Q64FV_OK ? ACK : NACK);
    } else {
        W25Q64FV_status_t status = W25Q64FV_erase_chip(true);
        uart_transmit(status == W25Q64FV_OK ? ACK : NACK);
    }
}

// one parameter is expected.
// size - in terms of page size. if 0 is given, all size 32768 is assumed
void bulk_read() {
    uint16_t size = receive_uint16();
    if (!size) {
        size = 32768;
    }
    for (int i = 0; i < size; i++) {
        uint32_t address = ((uint32_t)i) * PAGE_SIZE;
        W25Q64FV_status_t status = W25Q64FV_read_page(address, (byte*)buff, PAGE_SIZE);
        if (status == W25Q64FV_OK) {
            for (int j = 0; j < PAGE_SIZE; j++) {
                uart_transmit(buff[j]);
            }
            _delay_ms(1000);            
        } else {
            return; // Something went wrong, abort 
        }
    }
}

// two parameters are expected.
// offset - number of pages to skip.
// size - number of pages to write. if 0 is given, all size 32768 is assumed
void bulk_write() {
    uint16_t offs = receive_uint16();
    uint16_t size = receive_uint16();
    if (!size) {
        size = 32768;
    }
    for (int i = 0; i < size; i++) {
        for (int j = 0; j < PAGE_SIZE; j++) {
            while (!uart_available());
            buff[j] = uart_receive();
        }

        uint32_t address = ((uint32_t)(offs + i)) * PAGE_SIZE;
        W25Q64FV_enable_writing();
        W25Q64FV_write_page(address, (byte*)buff);
        W25Q64FV_status_t status = W25Q64FV_wait_until_free(W25Q64FV_DEFAULT_TIMEOUT);
        if (status == W25Q64FV_OK) {
            _delay_ms(1000);
            uart_transmit(ACK);
        } else {
            uart_transmit(NACK);
            return; // Something went wrong, abort 
        }
    }
}
#endif            

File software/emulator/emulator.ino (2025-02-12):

/*
RC6502 FLASH (W25Q64F) Card emulator
Copyright (c) 2025 Arvid Juskaitis

PORTD (Digital Pins 2–7):

    PD2: Digital Pin 2      29
    PD3: Digital Pin 3      30
    PD4: Digital Pin 4      31
    PD5: Digital Pin 5      32
    PD6: Digital Pin 6      33
    PD7: Digital Pin 7      34

PORTB (Digital Pins 8–13):

    PB0: Digital Pin 8      27
    PB1: Digital Pin 9      28
    PB2: Digital Pin 10     24
    PB3: Digital Pin 11     19
 */

#define BODT        0x80
#define EODT        0x8F
#define ACK         0xA0
#define NACK        0xAF

#define RDY_FLAG    (1 << 7)  // MCU sets if data is ready
#define BSY_FLAG    (1 << 6)  // MCU sets if busy
#define DAT_FLAG    (1 << 4)  // Data nibble flag

const int dataPins[] = {2, 3, 4, 5, 6, 7, 8, 9}; // PD2–PD7 for MS, PB0–PB1 for LS
const int rwPin = 10; // Read/Write control pin
const int phi2Pin = 11; // PHI2 clock signal pin

const char* usage = "Usage: wHH, wC, s, r, R, a, n, b, e, l, lr"; 
uint16_t log_buff[512];
uint16_t log_idx = 0;

void setup() {
    Serial.begin(38400);
    Serial.println(usage);

    pinModeData(INPUT);
    pinMode(rwPin, OUTPUT);
    pinMode(phi2Pin, OUTPUT);
    digitalWrite(rwPin, HIGH); // Default to read
    digitalWrite(phi2Pin, LOW); // Default clock low
}

void loop() {
    if (Serial.available() > 0) {
        String command = Serial.readStringUntil('\n');
        command.trim();
        if (command.startsWith("w")) {
            short len = command.length();
            if (len == 2) {
                byte data = command.charAt(1);
                wait_no_bsy();
                writeData(DAT_FLAG | ((data >> 4) & 0x0f));
                byte rx = wait_rdy_read();
                if (rx != ACK) {
                    Serial.print("RX: ");
                    print_hex(rx);
                    Serial.println();
                    return;
                }
                writeData(DAT_FLAG | (data & 0x0f));
            } else if (len == 3) {
                String hexValue = command.substring(1);
                byte data = strtol(hexValue.c_str(), NULL, 16);
                wait_no_bsy();
                writeData(data);
            }
        } else if (command == "a") {
            byte data = ACK; // 0xa0
            wait_no_bsy();
            writeData(data);
        } else if (command == "n") {
            byte data = NACK; // 0xaf
            wait_no_bsy();
            writeData(data);
        } else if (command == "b") {
            byte data = BODT; // 0x80
            wait_no_bsy();
            writeData(data);
        } else if (command == "e") {
            byte data = EODT; // 0x8f
            wait_no_bsy();
            writeData(data);
        } else if (command == "s") {
            byte data = readData();
            print_hex(data);
            Serial.print(", ");
            print_bin(data);
            Serial.println();
        } else if (command == "r") {
            byte data = wait_rdy_read();
            if (data != ACK) {
                wait_no_bsy();
                writeData(ACK);  // 0xa0
            }
            if (data & DAT_FLAG) {
                byte nibble = wait_rdy_read();
                wait_no_bsy();
                writeData(ACK);  // 0xa0
                data = ((data & 0x0f) << 4) | (nibble & 0x0f);
                if (data >= 0x20 && data <= 0x7f) {
                    Serial.print((char) data);
                } else {
                    print_hex(data);
                }
            } else {
                print_hex(data);
            }
            Serial.print(" ");
        } else if (command == "R") {
              while (true) {
                byte data = wait_rdy_read();
                wait_no_bsy();
                writeData(ACK);  // 0xa0
                if (data == EODT) break;
                if (data & DAT_FLAG) {
                    byte nibble = wait_rdy_read();
                    wait_no_bsy();
                    writeData(ACK);  // 0xa0
                    data = ((data & 0x0f) << 4) | (nibble & 0x0f);
                    if (data >= 0x20 && data <= 0x7f) {
                        Serial.print((char) data);
                    } else {
                        print_hex(data);
                    }
                } else {
                    print_hex(data);
                }
                Serial.print(" ");
            }
        } else if (command == "l") {
            log_print();
        } else if (command == "lr") {
            log_idx = 0;
        } else {
            Serial.print("Invalid command: ");
            Serial.print(command);
            Serial.print(", ");
            Serial.println(usage);
        }
    }
}

void print_hex(byte value) {
  if (value < 0x10) Serial.print('0');  
  Serial.print(value, HEX);
}

void print_bin(byte value) {
for (int i = 7; i >= 0; i--) {
    Serial.print((value >> i) & 1); 
  }  
}

void wait_no_bsy() {
    byte status;
    do
        status = readData();
    while ((status & BSY_FLAG) != 0);
    delay(10);
}

byte wait_rdy_read() {
    byte data;
    do
        data = readData();
    while ((data & RDY_FLAG) == 0);
    
    log(0, data);
    return data;
}

void pinModeData(short mode) {
    // Set all data pins (PD2–PD7 and PB0–PB1)
    if (mode == INPUT) {
        DDRD &= ~0b11111100; // Configure PD2–PD7 as input
        DDRB &= ~0b00000011; // Configure PB0–PB1 as input
    } else {
        DDRD |= 0b11111100; // Configure PD2–PD7 as output
        DDRB |= 0b00000011; // Configure PB0–PB1 as output
    }
}

void writeData(byte data) {
    log(1, data);

    pinModeData(OUTPUT);
    digitalWrite(rwPin, LOW); // Set to write

    // Write MS part (6 bits) to PD2–PD7
    PORTD = (PORTD & 0x03) | (data & 0xFC); // Clear PD2–PD7, set MS bits
    // Write LS part (2 bits) to PB0–PB1
    PORTB = (PORTB & 0xFC) | (data & 0x03); // Clear PB0–PB1, set LS bits

    // Simulate clock pulse
    PORTB |= (1 << PB3);  // Set PHI2 HIGH
    __asm__ __volatile__("nop\n nop\n nop\n nop\n"); // ~0.5 µs delay
    PORTB &= ~(1 << PB3); // Set PHI2 LOW
}

byte readData() {
    pinModeData(INPUT);
    digitalWrite(rwPin, HIGH); // Set to read

    // Simulate clock pulse
    PORTB |= (1 << PB3);  // Set PHI2 HIGH
    __asm__ __volatile__("nop\n nop\n"); // ~0.25 µs delay

    // Read MS part (6 bits) from PD2–PD7
    byte msPart = PIND & 0xFC; // Mask PD2–PD7
    // Read LS part (2 bits) from PB0–PB1
    byte lsPart = PINB & 0x03; // Mask PB0–PB1

    PORTB &= ~(1 << PB3); // Set PHI2 LOW

    delay(10);

    // Combine and return
    return msPart | lsPart;
}

void log(uint16_t rw, uint8_t data) {
    if (log_idx + 1 >= sizeof log_buff) {
        Serial.println("log buffer is full");
        return;
    }
    log_buff[log_idx ++] = (rw << 8) | data;
}
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

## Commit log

2025-02-12 add project files
    [BOB-12009.step, rc6502_fd.kicad_pcb, rc6502_fd.kicad_sch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]
2025-02-18 bugfixes in write operation
    [rc6502_fd.c]
